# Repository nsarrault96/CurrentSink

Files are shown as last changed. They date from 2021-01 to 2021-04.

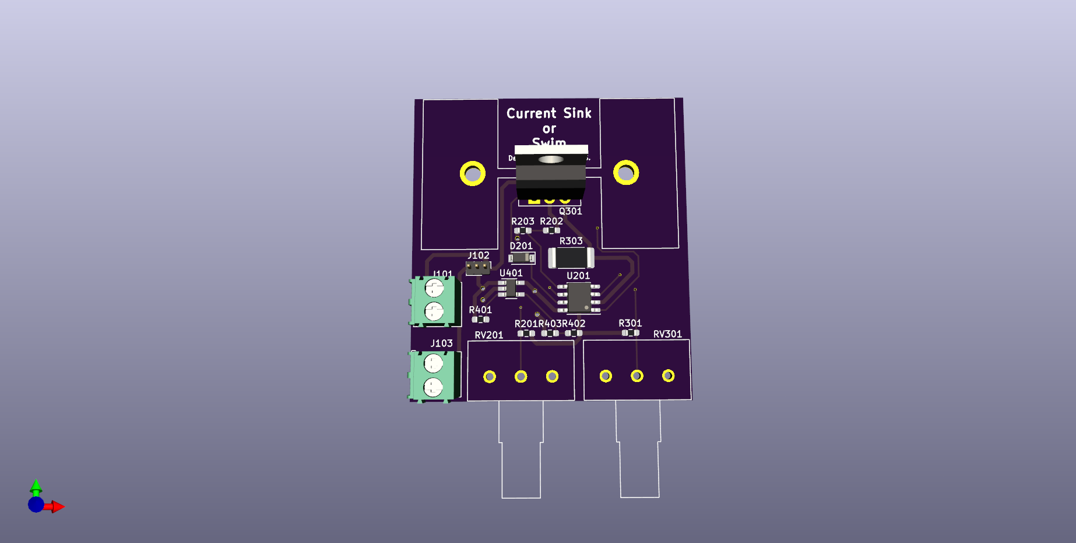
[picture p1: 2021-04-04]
CurrentSinkTop.png

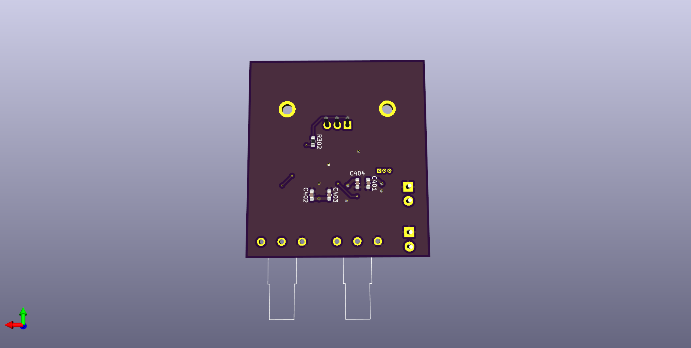
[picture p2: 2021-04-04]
CurrentSinkBottom.png

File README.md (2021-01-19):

# CurrentSink
My version of the Current Sink or Swim project from Contextual Electronics

<br/>

## Component Selection

### Op Amp<br/>
**Part Number:** MCP6002

<br/>

### Voltage Regulator<br/>
**Part Number:** MIC5205

<br/>

### Mosfet<br/>
**Part Number:** STP55FN06L

<br/>

### Heatsink<br/>
**Part Number:** 529702B02500G

<br/>

### Current Sense Resistor<br/>

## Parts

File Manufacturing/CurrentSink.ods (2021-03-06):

Reference | Value | MPN | Qty | Footprint | Datasheet
C401, C404 | 1uF |  | 2 | Capacitor_SMD:C_0603_1608Metric_Pad1.08x0.95mm_HandSolder | ~
C402 | 10uF |  | 1 | Capacitor_SMD:C_0603_1608Metric_Pad1.08x0.95mm_HandSolder | ~
C403 | 0.1uF |  | 1 | Capacitor_SMD:C_0603_1608Metric_Pad1.08x0.95mm_HandSolder | ~
D201 | 1N4148 |  | 1 | Diode_SMD:D_SOD-123 | ~
H301 | Heatsink | 529802B02500G | 1 | f:Heatsink | https://www.boydcorp.com/aavid-datasheets/Board-Level-Cooling-Extruded-5290.pdf
J101 | Tst | 1984617 | 1 | TerminalBlock_Phoenix:TerminalBlock_Phoenix_PT-1,5-2-3.5-H_1x02_P3.50mm_Horizontal | https://media.digikey.com/pdf/Data%20Sheets/Phoenix%20Contact%20PDFs/Combicon%20Compact%20Series.pdf
J102 | pwrJmp |  | 1 | Connector_PinHeader_1.27mm:PinHeader_1x03_P1.27mm_Vertical | ~
J103 | Pwr | 1984617 | 1 | TerminalBlock_Phoenix:TerminalBlock_Phoenix_PT-1,5-2-3.5-H_1x02_P3.50mm_Horizontal | https://media.digikey.com/pdf/Data%20Sheets/Phoenix%20Contact%20PDFs/Combicon%20Compact%20Series.pdf
Q301 | STP60NF06L | STP60NF06L | 1 | Package_TO_SOT_THT:TO-220-3_Vertical | https://www.st.com/content/ccc/resource/technical/document/datasheet/57/fb/ac/00/b5/ba/4f/e7/CD00002907.pdf/files/CD00002907.pdf/jcr:content/translations/en.C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
R201, R203, R302 | 1K |  | 3 | Resistor_SMD:R_0603_1608Metric_Pad0.98x0.95mm_HandSolder | ~
R202 | 9K |  | 1 | Resistor_SMD:R_0603_1608Metric_Pad0.98x0.95mm_HandSolder | ~
R301 | 6.2K |  | 1 | Resistor_SMD:R_0603_1608Metric_Pad0.98x0.95mm_HandSolder | ~
R303 | 0.1 | CRA2512-FZ-R100ELF | 1 | Resistor_SMD:R_2512_6332Metric_Pad1.40x3.35mm_HandSolder | https://www.bourns.com/docs/product-datasheets/cra.pdf
R401 | 0 |  | 1 | Resistor_SMD:R_0603_1608Metric_Pad0.98x0.95mm_HandSolder | ~
R402, R403 | 10K |  | 2 | Resistor_SMD:R_0603_1608Metric_Pad0.98x0.95mm_HandSolder | ~
RV201, RV301 | 10K | P160KN-0QD15B10K | 2 | f:POT_TTElect_P160KN | https://www.ttelectronics.com/TTElectronics/media/ProductFiles/Potentiometers/Datasheets/P160.pdf
U201 | MCP6002 | MCP6002T-I/SN | 1 | Package_SO:SOIC-8_3.9x4.9mm_P1.27mm | http://ww1.microchip.com/downloads/en/DeviceDoc/21733j.pdf
U401 | TPS7A2401 | TPS7A2401DBVR | 1 | Package_TO_SOT_SMD:SOT-23-5_HandSoldering | https://www.ti.com/lit/ds/symlink/tps7a24.pdf?HQS=dis-dk-null-digikeymode-dsf-pf-null-wwe&ts=1613174744075

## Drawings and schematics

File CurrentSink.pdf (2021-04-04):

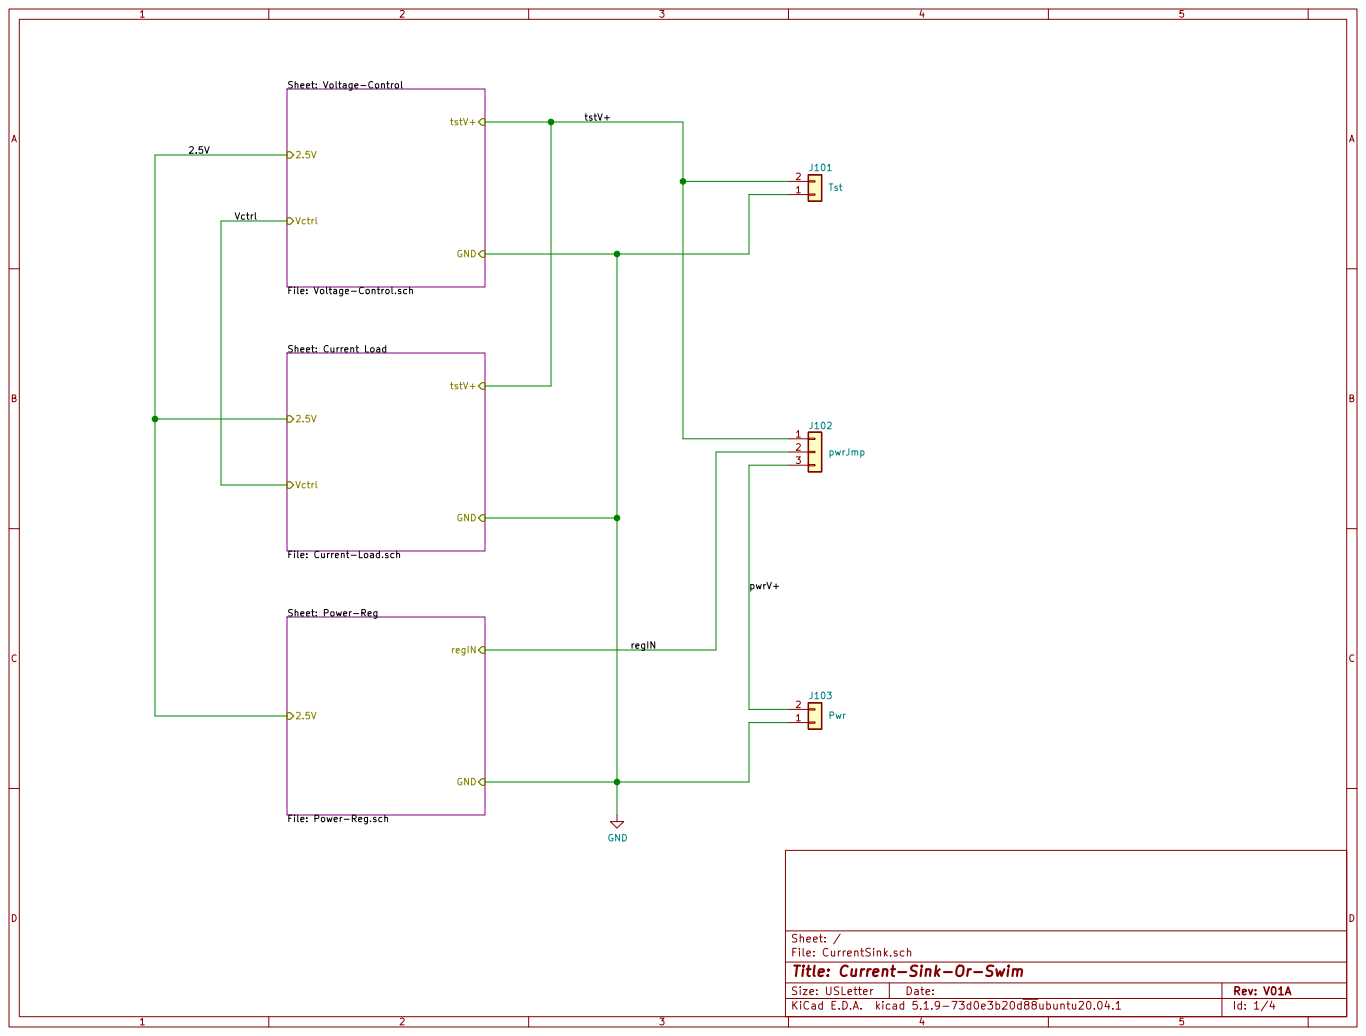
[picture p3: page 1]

File: Voltage-Control.sch

File: Power-Reg.sch

File: CurrentSink.sch Sheet: /
Id: 1/4 Title: Current-Sink-Or-Swim

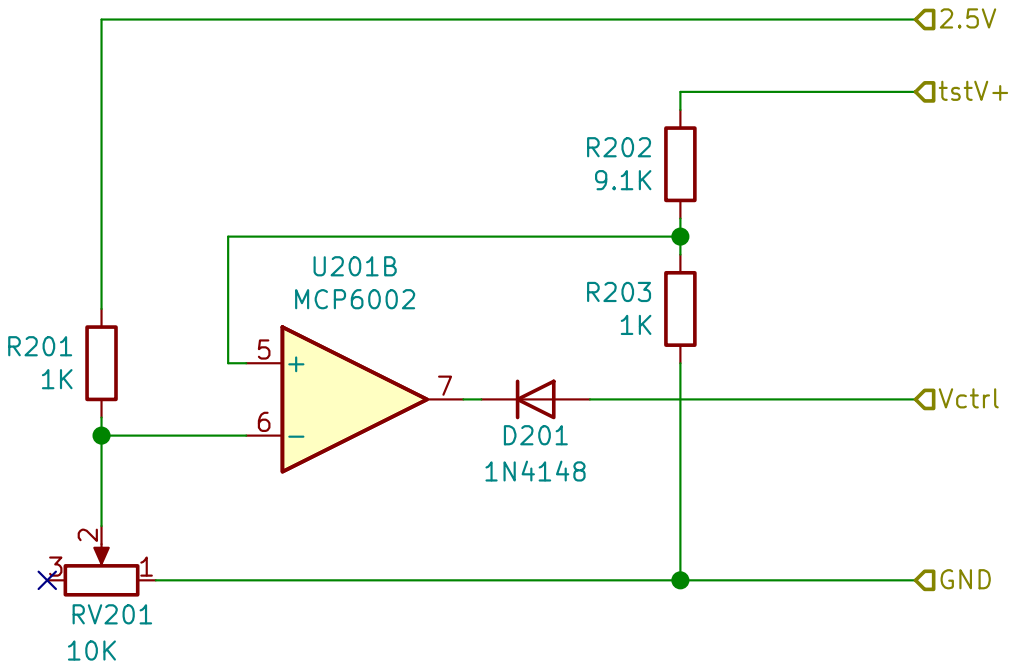
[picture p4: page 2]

Sheet: /Voltage-Control/
File: Voltage-Control.sch
Id: 2/4 Title:

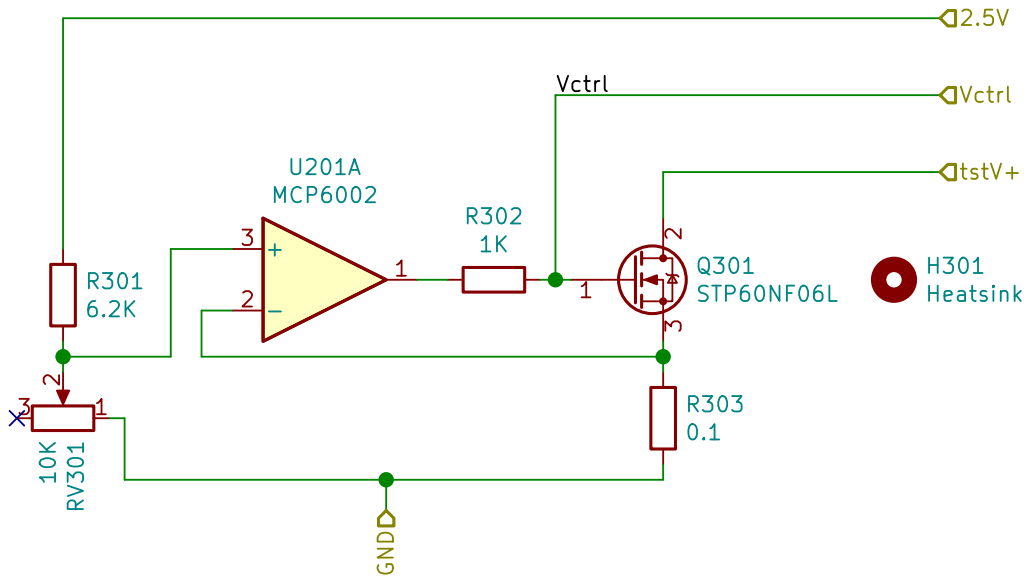
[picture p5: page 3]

Id: 3/4 Title: File: Current-Load.sch Sheet: /Current Load/ R303

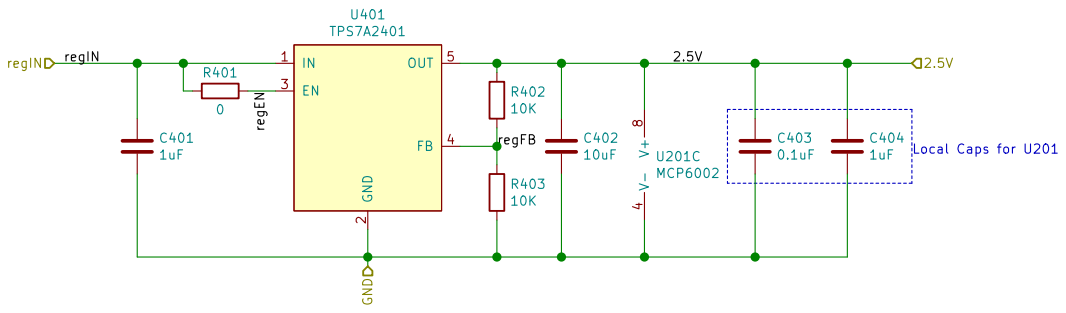
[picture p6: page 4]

2 EN 3 FB 4 OUT 5 U401 TPS7A2401 GND

Sheet: /Power-Reg/
File: Power-Reg.sch
Id: 4/4 Title:

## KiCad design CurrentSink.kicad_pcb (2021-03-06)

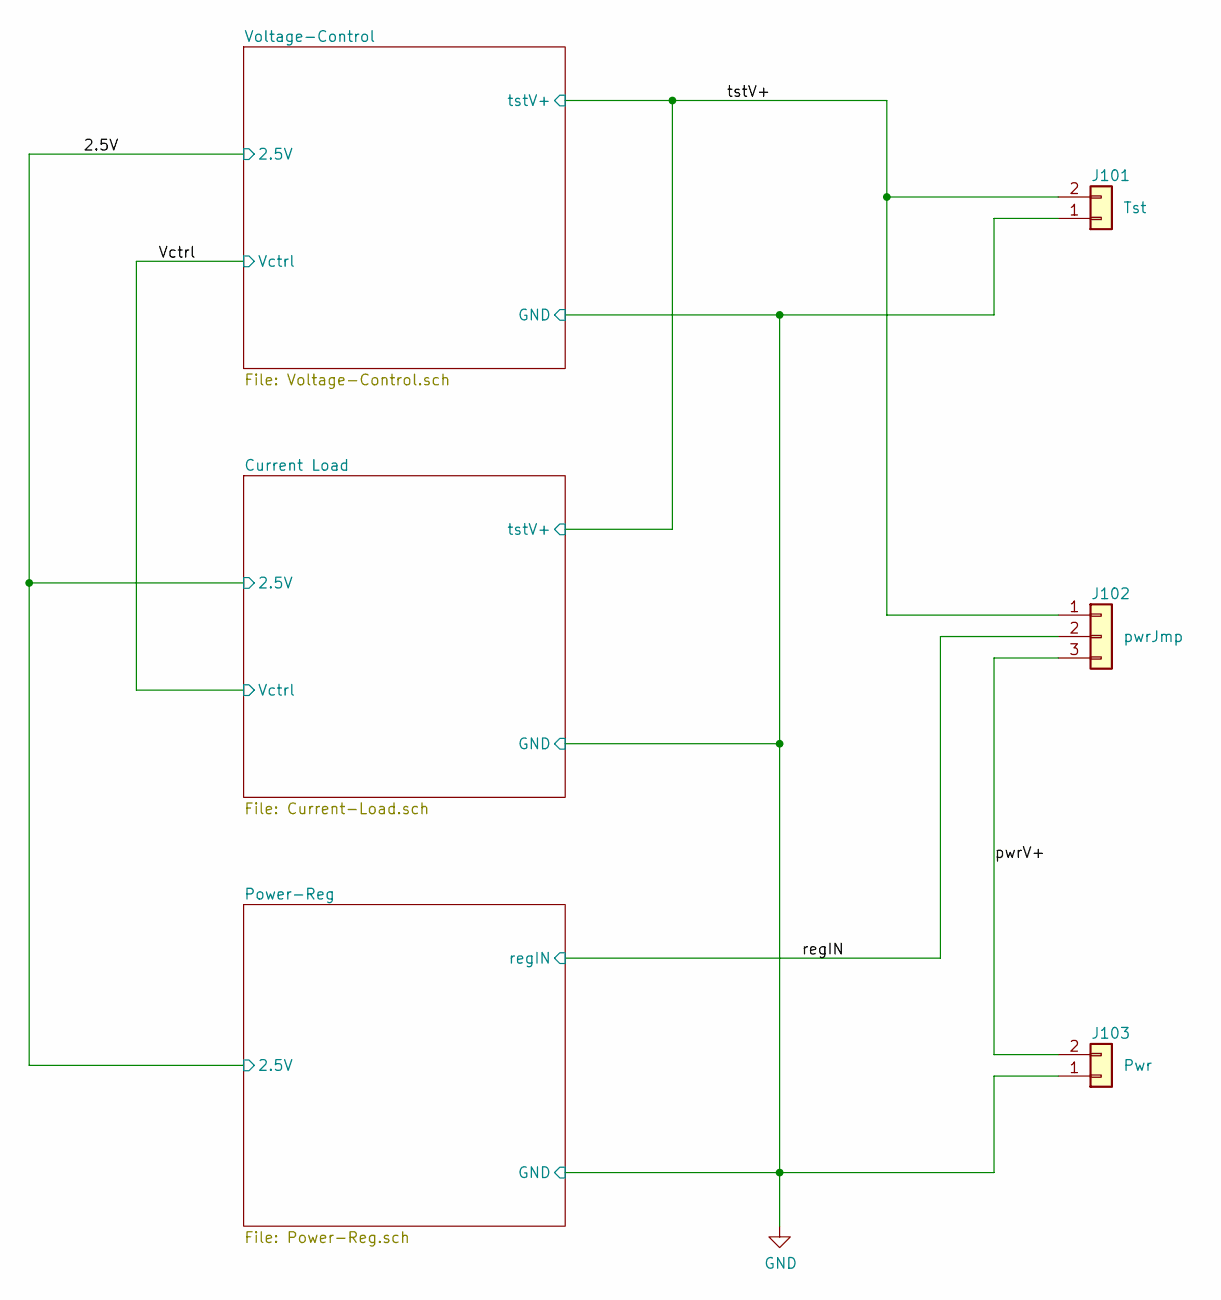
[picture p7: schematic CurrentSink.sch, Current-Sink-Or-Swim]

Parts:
J101: Tst; TerminalBlock_Phoenix_PT-1,5-2-3.5-H_1x02_P3.50mm_Horizontal; MPN 1984617
J102: pwrJmp; PinHeader_1x03_P1.27mm_Vertical
J103: Pwr; TerminalBlock_Phoenix_PT-1,5-2-3.5-H_1x02_P3.50mm_Horizontal; MPN 1984617

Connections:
/pwrV+: J102.3, J103.2
/regIN: J102.2; also elsewhere on the board
/tstV+: J101.2, J102.1; also elsewhere on the board
GND: J101.1, J103.1; also elsewhere on the board

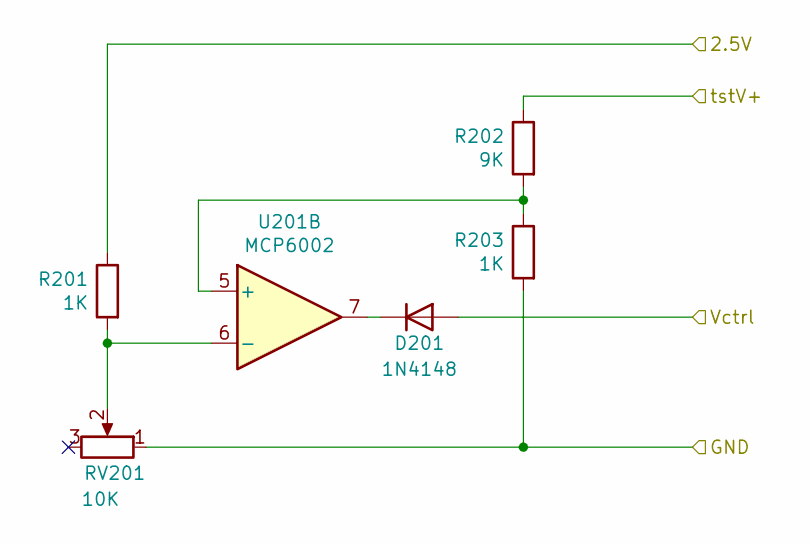
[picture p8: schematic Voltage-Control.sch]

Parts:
D201: 1N4148; D_SOD-123
R201, R203: 1K; R_0603_1608Metric_Pad0.98x0.95mm_HandSolder
R202: 9K; R_0603_1608Metric_Pad0.98x0.95mm_HandSolder
RV201: 10K; POT_TTElect_P160KN; MPN P160KN-0QD15B10K
U201: MCP6002; SOIC-8_3.9x4.9mm_P1.27mm; MPN MCP6002T-I/SN

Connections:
/2.5V: R201.1; also elsewhere on the board
/Vctrl: D201.2 (A); also elsewhere on the board
/tstV+: R202.1; also elsewhere on the board
GND: R203.2, RV201.1; also elsewhere on the board
unnamed: D201.1 (K), U201.7
unnamed: R201.2, RV201.2, U201.6 (-)
unnamed: R202.2, R203.1, U201.5 (+)

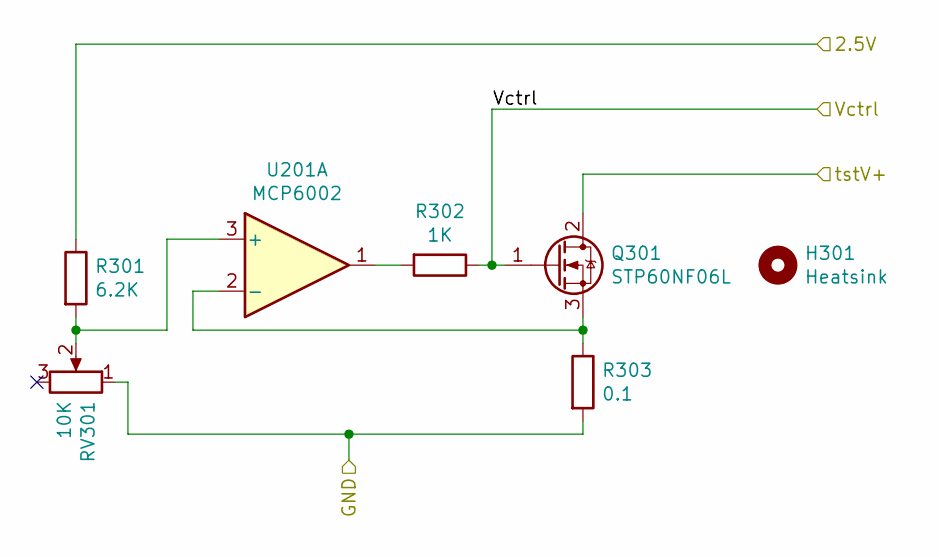
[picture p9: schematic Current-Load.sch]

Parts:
H301: Heatsink; MPN 529802B02500G
Q301: STP60NF06L; TO-220-3_Vertical; MPN STP60NF06L
R301: 6.2K; R_0603_1608Metric_Pad0.98x0.95mm_HandSolder
R302: 1K; R_0603_1608Metric_Pad0.98x0.95mm_HandSolder
R303: 0.1; R_2512_6332Metric_Pad1.40x3.35mm_HandSolder; MPN CRA2512-FZ-R100ELF
RV301: 10K; POT_TTElect_P160KN; MPN P160KN-0QD15B10K
U201: MCP6002; SOIC-8_3.9x4.9mm_P1.27mm; MPN MCP6002T-I/SN

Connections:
/2.5V: R301.1; also elsewhere on the board
/Vctrl: Q301.1 (G), R302.1; also elsewhere on the board
/tstV+: Q301.2 (D); also elsewhere on the board
GND: R303.2, RV301.1; also elsewhere on the board
unnamed: Q301.3 (S), R303.1, U201.2 (-)
unnamed: R301.2, RV301.2, U201.3 (+)
unnamed: R302.2, U201.1

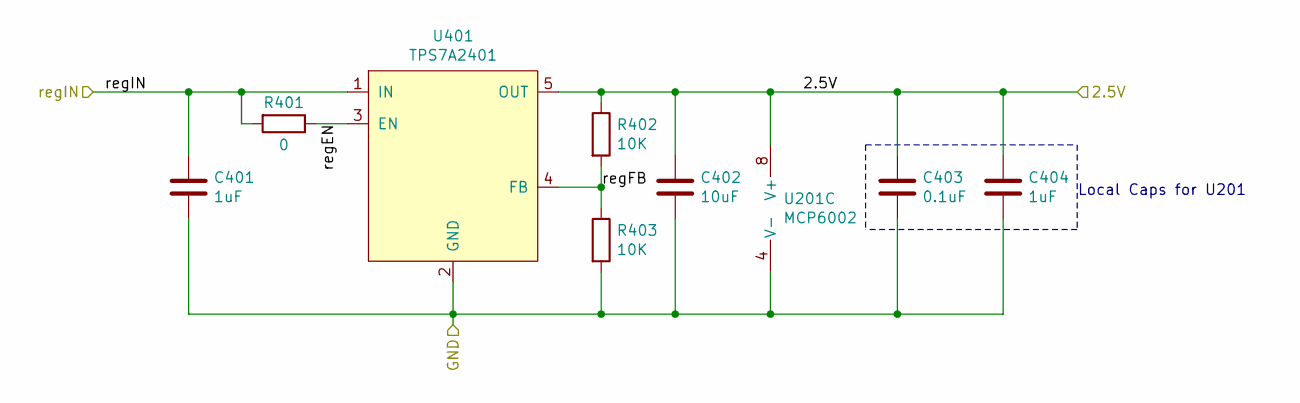
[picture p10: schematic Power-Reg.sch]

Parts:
C401, C404: 1uF; C_0603_1608Metric_Pad1.08x0.95mm_HandSolder
C402: 10uF; C_0603_1608Metric_Pad1.08x0.95mm_HandSolder
C403: 0.1uF; C_0603_1608Metric_Pad1.08x0.95mm_HandSolder
R401: 0; R_0603_1608Metric_Pad0.98x0.95mm_HandSolder
R402, R403: 10K; R_0603_1608Metric_Pad0.98x0.95mm_HandSolder
U201: MCP6002; SOIC-8_3.9x4.9mm_P1.27mm; MPN MCP6002T-I/SN
U401: TPS7A2401; SOT-23-5_HandSoldering; MPN TPS7A2401DBVR

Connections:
/2.5V: C402.1, C403.1, C404.1, R402.1, U201.8 (V+), U401.5 (OUT); also elsewhere on the board
/Power-Reg/regEN: R401.1, U401.3 (EN)
/Power-Reg/regFB: R402.2, R403.1, U401.4 (FB)
/regIN: C401.1, R401.2, U401.1 (IN); also elsewhere on the board
GND: C401.2, C402.2, C403.2, C404.2, R403.2, U201.4 (V-), U401.2 (GND); also elsewhere on the board

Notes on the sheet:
Local Caps for U201

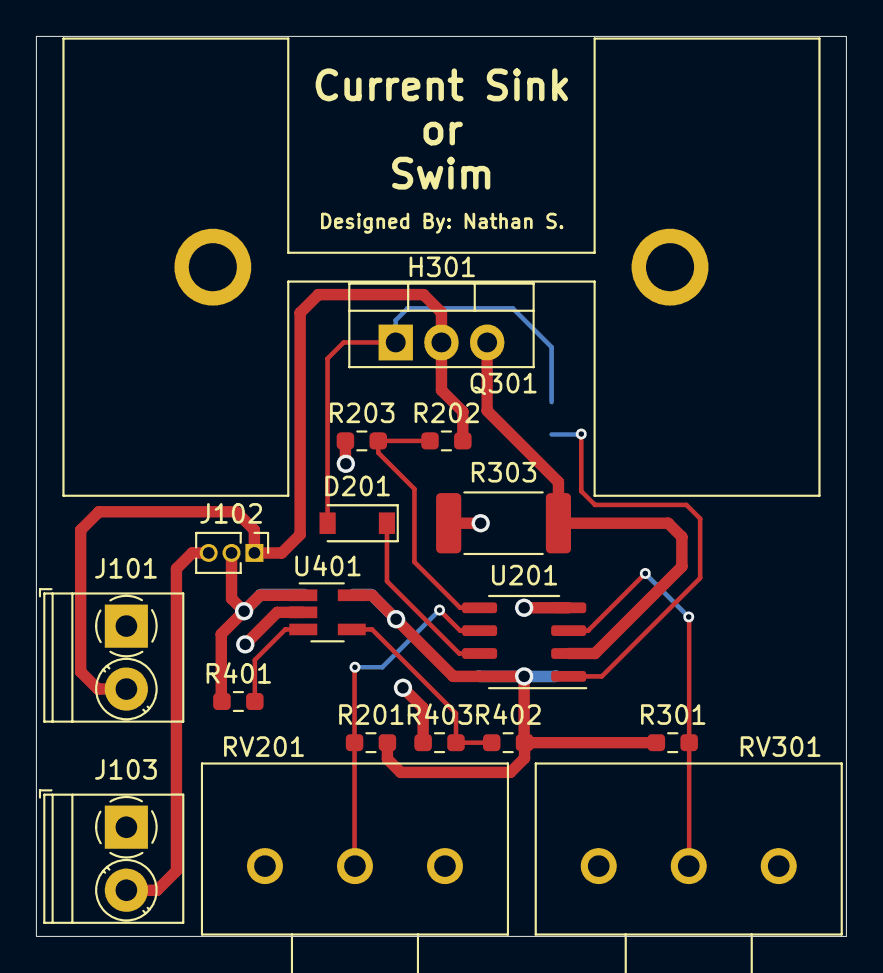
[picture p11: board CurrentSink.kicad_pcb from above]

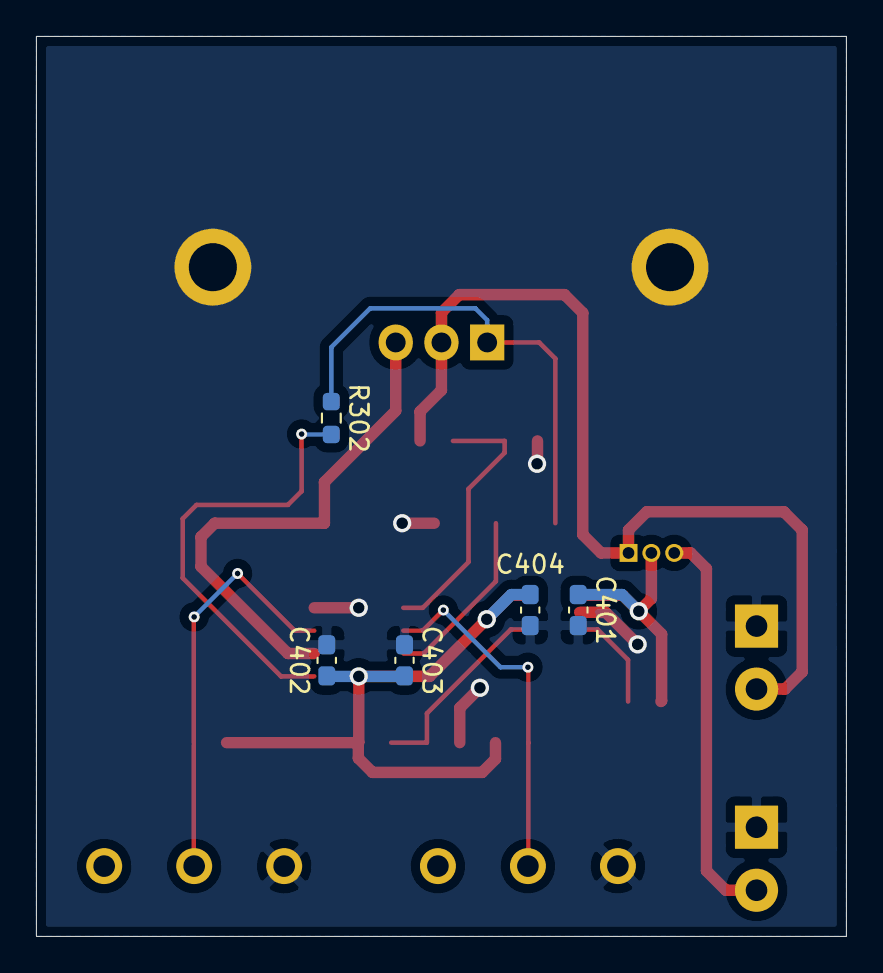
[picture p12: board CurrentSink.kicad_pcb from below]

Board: 2 copper layers, 45.0 x 50.0 mm, 23 parts (5 on the bottom side), 14 nets.

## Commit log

2021-01-19 Adding all Kicad files & folders for the project
    [CurrentSink.kicad_pcb, CurrentSink.sch]
2021-01-20 Adding the beginning schematic and Datasheets
    [CurrentSink.sch]
2021-01-25 Updating the Schematic
    [CurrentSink.sch]
2021-02-03 Schematic final version and preliminary footprints
    [CurrentSink.sch]
2021-02-03 Adding missing files
    [Currrent-Load.sch, Power-Reg.sch, Voltage-Control.sch]
2021-02-08 Removing files before creating .gitignore file
    [CurrentSink.kicad_pcb]
2021-02-08 Added .gitignore and heatsink datasheet
2021-02-08 Fixed typo in Current-Load schematic sheet
    [CurrentSink.sch]
2021-02-08 Fixing Type in Current-Load schematic again
    [Current-Load.sch]
2021-02-08 Added heatsink to schematic and PCB
    [Current-Load.sch, CurrentSink.kicad_pcb]
2021-02-09 Initial PCB component Placement
    [CurrentSink.kicad_pcb]
2021-03-01 PCB completed with Op-Amp mounted horizontally
    [Current-Load.sch, CurrentSink.kicad_pcb, CurrentSink.sch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]
2021-03-01 Changed the Op-Amp to be vertical and switched the power input side
    [CurrentSink.kicad_pcb]
2021-03-04 All component placements complete, silk screen cleaned up, and tracks routed. DRC passed.
    [CurrentSink.kicad_pcb]
2021-03-06 Revision A as sent to OSHPark with some MPN updates due to availability
    [Current-Load.sch, CurrentSink.kicad_pcb, Power-Reg.sch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]
2021-03-06 Revision 1 release
    [CurrentSink.ods, Power-Reg.sch, Voltage-Control.sch]
2021-04-04 Fixed reversed Op-Amp for voltage limiting and potentiometer connections to allow for full range of the potentiometer.
    [Current-Load.sch, CurrentSink.sch, Voltage-Control.sch]
